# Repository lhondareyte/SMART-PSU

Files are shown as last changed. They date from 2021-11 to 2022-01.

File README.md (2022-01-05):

# SMART PSU for ARM SBC
This is a smart power switch for ARM SBC. This provides a gracefull shutdown and power-off for any tiny board computer that support FreeBSD+libgpio.

This tested OK on 
* Nanopi Neo
* Nanopi Neo Air
* Orange PI
* Raspberry PI B
* Raspberry PI 3

## How it's work?
When plugging in, the board is poweroff and the switch device enter in sleep mode to reduce power consumption.  Just press the switch to power on the board. If you press again the button within 1.5 seconds, the board is poweroff immediatly. 

In normal operation (when operating system is running), the ```psud``` daemon wait for key pressed to perform specified action. The default configuration file is as follow:

```
# psud configuration file
# $Id$  /etc/psud.conf
PSUD_PIN=3                       # My configuration on NanoPI Neo
PSUD_CMD="/sbin/shutdown -p now"	
PSUD_OPT="Dont Care"             # Nothing special
```
In ```/etc/rc.conf```, adds the following line

```
psud_enable="YES"
```
Start ```psud``` 

```
service psud start
```
So, just press button to gracefully shutdown the system. After the configured delay (by dip-switch), the board is powered-off.

## AC Recovery mode
AC Power Recovery
Allows you to set how the system reacts after AC power is restored to the system. By default, the AC Power Recovery option is set to "Power OFF". The other option is "last state".

## Nanobsd configuration
Since all persistents filesystems are mount read-only, there is no need for graceful shutdown with nanobsd. But you probably need to save your configuration on shutdown. You can achieve this with the following script:

```
#!/bin/sh
#
# file: /usr/local/bin/save_configuration.sh
#
mount /cfg || exit 1
find /cfg -type f -print | sed -e '/^\/cfg//' | while read f
do
	if [ -f /etc/$f ] ; then
		cp -p /etc/$f /cfg/$f
	fi
done
sync;sync;sync
umount /cfg
```
Edit ```/etc/psud.conf``` as follows:

```
PSUD_PIN=1                    # Power switch pin, hardware dependent
PSUD_CMD="/usr/local/bin/save_configuration.sh"

PSUD_OPT="WaitAndShot"        # Wait for $PSUD_CMD to complete before
                              # poweroff. GPIO pin is toggle to HIGH 
                              # after $CMD complete . Any other option
                              # is ignored and power off is achieved after
                              # $SHUTDOWN_TIMEOUT
```

## About files
```
 psud/        psud daemon sources
 kicad/       KiCad schematic
 firmware/    source code for AVR attiny13/13a and atmega328p
 refs/        Some MOSFET-P datasheets
```

## LICENSE
Released under the MIT License

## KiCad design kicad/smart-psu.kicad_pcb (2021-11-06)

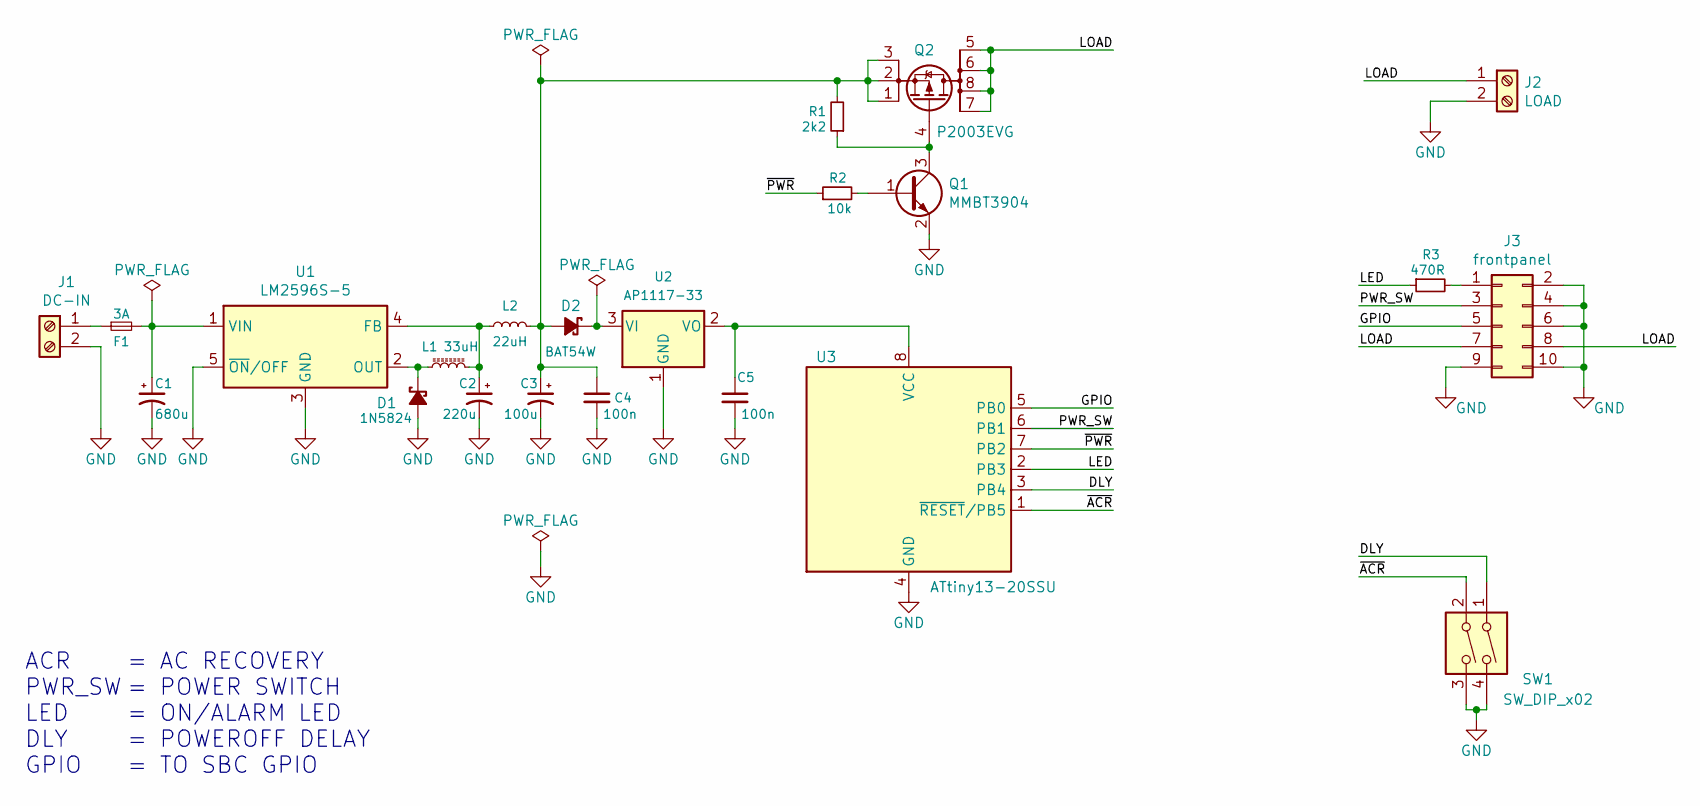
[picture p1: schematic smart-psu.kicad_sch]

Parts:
C1: 680u; C_Radial_D10.0mm_H20.0mm_P5.00mm
C2: 220u; CP_Radial_D8.0mm_P2.50mm
C3: 100u; CP_Radial_D5.0mm_P2.50mm
C4, C5: 100n; C_1206_3216Metric_Pad1.33x1.80mm_HandSolder
D1: 1N5824; D_A-405_P12.70mm_Horizontal
D2: BAT54W; D_1206_3216Metric_Pad1.42x1.75mm_HandSolder
F1: 3A; Fuse_1206_3216Metric_Pad1.42x1.75mm_HandSolder
J1: DC-IN; TerminalBlock_MetzConnect_Type055_RT01502HDWU_1x02_P5.00mm_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
J2: LOAD; TerminalBlock_MetzConnect_Type055_RT01502HDWU_1x02_P5.00mm_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
J3: frontpanel; PinHeader_2x05_P2.54mm_Vertical
L1: 33uH; L_Toroid_Vertical_L21.6mm_W11.4mm_P7.62mm_Pulse_KM-3
L2: 22uH; L_Toroid_Vertical_L21.6mm_W11.4mm_P7.62mm_Pulse_KM-3
Q1: MMBT3904; SOT-23
Q2: P2003EVG; SOIC-8_3.9x4.9mm_P1.27mm
R1: 2k2; R_1206_3216Metric_Pad1.30x1.75mm_HandSolder
R2: 10k; R_1206_3216Metric_Pad1.30x1.75mm_HandSolder
R3: 470R; R_1206_3216Metric_Pad1.30x1.75mm_HandSolder
SW1: SW_DIP_x02; SW_DIP_SPSTx02_Slide_9.78x7.26mm_W7.62mm_P2.54mm
U1: LM2596S-5; TO-263-5_TabPin3
U2: AP1117-33; SOT-223-3_TabPin2
U3: ATtiny13-20SSU; SOIC-8_3.9x4.9mm_P1.27mm

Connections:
/DLY: SW1.1, U3.3 (PB4)
/GPIO: J3.5, U3.5 (PB0)
/LED: R3.1, U3.2 (PB3)
/LOAD: J2.1, J3.7, J3.8, Q2.5 (D), Q2.6 (D), Q2.7 (D), Q2.8 (D)
/PWR_SW: J3.3, U3.6 (PB1)
/~ACR: SW1.2, U3.1 (~RESET/PB5)
/~PWR: R2.1, U3.7 (PB2)
GND: C1.2, C2.2, C3.2, C4.2, C5.2, D1.2 (A), J1.2, J2.2, J3.2, J3.4, J3.6, J3.9, J3.10, Q1.2 (E), SW1.3, SW1.4, U1.3 (GND), U1.5 (~ON/OFF), U2.1 (GND), U3.4 (GND)
unnamed: C1.1, F1.2, U1.1 (VIN)
unnamed: C2.1, L1.2, L2.2, U1.4 (FB)
unnamed: C3.1, C4.1, D2.2 (A), L2.1, Q2.1 (S), Q2.2 (S), Q2.3 (S), R1.2
unnamed: C5.1, U2.2 (VO), U3.8 (VCC)
unnamed: D1.1 (K), L1.1, U1.2 (OUT)
unnamed: D2.1 (K), U2.3 (VI)
unnamed: F1.1, J1.1
unnamed: J3.1, R3.2
unnamed: Q1.1 (B), R2.2
unnamed: Q1.3 (C), Q2.4 (G), R1.1

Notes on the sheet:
ACR PWR_SW LED DLY GPIO
= AC RECOVERY = POWER SWITCH = ON/ALARM LED = POWEROFF DELAY = TO SBC GPIO

Board: 2 copper layers, 22 parts (0 on the bottom side), 18 nets, no tracks yet.

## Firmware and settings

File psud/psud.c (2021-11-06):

/*
 * Copyright (c) 2018-2021 Luc Hondareyte
 *
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
 * THE SOFTWARE IS PROVIDED "AS IS", WITHOUT WARRANTY OF ANY KIND, EXPRESS OR
 * IMPLIED, INCLUDING BUT NOT LIMITED TO THE WARRANTIES OF MERCHANTABILITY,
 * FITNESS FOR A PARTICULAR PURPOSE AND NONINFRINGEMENT. IN NO EVENT SHALL THE
 * AUTHORS OR COPYRIGHT HOLDERS BE LIABLE FOR ANY CLAIM, DAMAGES OR OTHER
 * LIABILITY, WHETHER IN AN ACTION OF CONTRACT, TORT OR OTHERWISE, ARISING FROM,
 * OUT OF OR IN CONNECTION WITH THE SOFTWARE OR THE USE OR OTHER DEALINGS IN THE
 * SOFTWARE.
 */

#include <stdlib.h>
#include <stdio.h>
#include <unistd.h>
#include <libgpio.h>
#include <time.h>
#include <sys/time.h>
#include <sys/resource.h>
#include <signal.h>
#include <sys/file.h>
#include <sys/types.h>
#include <sys/wait.h>
#include <syslog.h>

#include "psud.h"
#include "config.h"

FILE *lockfile;

struct config psu_config;

void psud_quit(int r) {
	if ( r == SIGHUP ) {
		get_config(CONFILE, &psu_config);
		syslog(LOG_NOTICE,"Waiting on pin %s for action (%s/%s).\n", psu_config.pin, psu_config.cmd, psu_config.opt);
		return;
	}
	syslog(LOG_NOTICE,"Signal received (%d), quitting.\n", r);
	fclose(lockfile);
	remove (LOCK);
	closelog();
	exit(0);
}

int main(int argc, char **argv) {

	int status=0;

	/*
	 * Open exclusive lock file to avoid multiple instances of daemon
	 */
	if (( lockfile = fopen(LOCK, "w")) == NULL) {
		perror(LOCK);
		return 1;
	}
	if (flock (fileno(lockfile), LOCK_EX | LOCK_NB) == -1) {
		perror (LOCK);
		return 1;
	}

	/*
	 * Getting valid configuration
	 */
	if (( get_config(CONFILE, &psu_config)) == -1 ) {
		fprintf (stderr, "Error getting configuration.\n");
		return 1;
	}

	/*
	 * Logging
	 */
	openlog("psud", LOG_PID|LOG_NDELAY, LOG_DAEMON),
		syslog(LOG_NOTICE, "Starting daemon.\n");

	/*
	 * Signals handling
	 */
	signal(SIGHUP, psud_quit);
	signal(SIGINT, psud_quit);
	signal(SIGTERM, psud_quit);

	/*
	 * Daemonize
	 */
	pid_t process_id=0;
	if ((process_id = fork()) < 0) {
		perror("fork");
		exit(1);
	}
	// Kill parent process
	if (process_id > 0 )
		exit(0);

	/*
	 * Writing pid to lockfile
	 */
	setvbuf (lockfile, (char*)NULL, _IONBF, 0);
	pid_t pid=getpid();
	fprintf(lockfile, "%d", pid);
	setpriority(PRIO_PROCESS, pid, 20);

	/*
	 * Ready to run. 
	 */
	int psu_pin = atoi(psu_config.pin);
	int buttonstate=UP;
	gpio_handle_t handle;
	if (( handle = gpio_open(0)) == -1) {
		syslog(LOG_NOTICE,"Error : No GPIO found on this platform.\n");
		//psud_quit(15);
	}

	gpio_pin_input(handle, psu_pin);
	gpio_pin_low(handle, psu_pin);
	gpio_pin_pullup(handle, psu_pin);

	syslog(LOG_NOTICE,"Waiting on pin %s for action (%s/%s).\n", psu_config.pin, psu_config.cmd, psu_config.opt);

	// Polling for key pressed
	while(1) {
		buttonstate = gpio_pin_get(handle, psu_pin);
		if ( buttonstate == DOWN ) {

			pid_t pid=0;
			if ((pid = fork()) == -1)
				perror("fork error");
			else if (pid == 0) {
				syslog(LOG_NOTICE, "GPIO %d toggle: Executing PSUD_CMD (%s).\n", psu_pin, (char*)psu_config.cmd);
				execl("/bin/sh", "sh", "-c", (char*)psu_config.cmd, NULL);
				syslog(LOG_NOTICE, "execl error\n");
				continue;

			} 
			if (strcmp(psu_config.opt, "WaitAndShoot") == 0 ) {
				syslog(LOG_NOTICE, "Waiting for child process(%d).\n", pid);
				waitpid(pid, NULL, WEXITED);
				// Toggle pin from ouput and high level to shutoff
				gpio_pin_output(handle, psu_pin);
				gpio_pin_high(handle, psu_pin);
				psud_quit(15);
			}
			wait(&status);
		}
		usleep(250000);
	}	
}

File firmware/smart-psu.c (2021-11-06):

/*
 * Copyright (c) 2018-2021 Luc Hondareyte
 *
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
 * THE SOFTWARE IS PROVIDED "AS IS", WITHOUT WARRANTY OF ANY KIND, EXPRESS OR
 * IMPLIED, INCLUDING BUT NOT LIMITED TO THE WARRANTIES OF MERCHANTABILITY,
 * FITNESS FOR A PARTICULAR PURPOSE AND NONINFRINGEMENT. IN NO EVENT SHALL THE
 * AUTHORS OR COPYRIGHT HOLDERS BE LIABLE FOR ANY CLAIM, DAMAGES OR OTHER
 * LIABILITY, WHETHER IN AN ACTION OF CONTRACT, TORT OR OTHERWISE, ARISING FROM,
 * OUT OF OR IN CONNECTION WITH THE SOFTWARE OR THE USE OR OTHER DEALINGS IN THE
 * SOFTWARE.
 */
/*
 * POWER BUTTON - AVR Version
 *
 * Copyright (c)2018-2021, Luc Hondareyte
 * All rights reserved.
 *
 * $Id$
 */

#include "smart-psu.h"

uint8_t pwr_state=OFF;
uint8_t os_is_running=NO;

void ms_wait (uint8_t n) {
	while (n) {
		_delay_us(1000);
		n--;
	}
}

inline void shutdown (void) {
#if defined (__BREADBOARD__)
	setBit(O_PORT,GPIO);
	ms_wait(250);
	clearBit(O_PORT,GPIO);
#else
	clearBit(O_PORT,GPIO);
	ms_wait(250);
	setBit(O_PORT,GPIO);
#endif
	ms_wait(250);
	clearBit(D_PORT,GPIO);    // Wait feedback from SBC
}

inline void PowerOff (void) {
	clearBit(O_PORT,GPIO);
	setBit(D_PORT,GPIO);      // no need feedback from SBC
	switchOff();
}

void startTimer (uint16_t n) {
	ms_seconds = n;
	ticks = 0;
	// No prescaler
	TCCR0B = 0x01;
}

void stopTimer(void) {
	ms_seconds = 0x0000;
	ticks = 0;
	TCCR0B = 0x00;
}

/* Blinking a led */

inline void blink (uint8_t pin, uint8_t n) {
	while(n) {
		ms_wait(250);
		toggleBit(O_PORT, pin);
		n--;
	}
	clearBit(O_PORT, pin);
}

void setupHardware (void ) {

        // Set ports direction
        setBit(D_PORT,FAULT);     // Fault alarm
        setBit(D_PORT,PWR);       // MOSFET Trigger
        setBit(D_PORT,GPIO);      // To SBC GPIO
        clearBit(D_PORT,PWR_SW);  // Power switch
        clearBit(D_PORT,ACR);     // AC Recovery mode
        // Pullup resistor on input pins
        setBit(O_PORT,PWR_SW);
        setBit(O_PORT,ACR);

        // Configure INT0
        clearBit(INTRGST,ISC00);
        clearBit(INTRGST,ISC01);
        enable_INT0();
#if defined (__BREADBOARD__)
        CLKPR=0x00;
#endif

        // Configure TIMER0 interuption
        TIMSK0 |= (1<<TOIE0);
}

ISR (INT0_vect) {
	// Wake-up MCU on key pressed
}

#if defined (__AVR_ATtiny13A__) || defined (__AVR_ATtiny13__)
ISR (TIM0_OVF_vect)
#else
ISR (TIMER0_OVF_vect)
#endif
{
	ticks++;
	if ( ticks == TICKS ) {
		ticks = 0;
		ms_seconds--;
	}
}

static void Power (void) {

	/*  Board is ON */

	if (pwr_state == ON) {
		if (os_is_running == YES) {
			setBit(O_PORT,FAULT);
			shutdown();
			startTimer(SHUTDOWN_TIMEOUT);
			while ( ms_seconds > 0 ) {
				if (bit_is_set(I_PORT,GPIO)) {
					stopTimer();
				       	break;
				}
			}
			pwr_state=OFF;
#if defined (__AC_RECOVERY__)
			saveConfiguration(pwr_state);
#endif
			os_is_running=NO;
			clearBit(O_PORT,FAULT);
			PowerOff();
			clearBit(O_PORT,FAULT);
		}
	
	}
	/* Board is OFF */
	else {
		switchOn();
		pwr_state=ON;
#if defined (__AC_RECOVERY__)
		saveConfiguration(pwr_state);
#endif
		loop_until_bit_is_set(I_PORT,PWR_SW);
		ms_wait(250);
		os_is_running=YES;
		startTimer(STARTUP_TIMEOUT);
#if defined (__BREADBOARD__)
		setBit(O_PORT,FAULT);
#endif
		while (ms_seconds > 0) {
			if ( bit_is_clear(I_PORT,PWR_SW)) {
				stopTimer();
				pwr_state=OFF;
#if defined (__AC_RECOVERY__)
				saveConfiguration(pwr_state);
#endif
				switchOff();
				alarm(10);
				break;
			}
		}
#if defined (__BREADBOARD__)
		clearBit(O_PORT,FAULT);
#endif
	}
	stopTimer();
}

int main(void) {

	ticks = 0;
	ms_seconds = 0;
	setupHardware();

	/* Wait for PSU stabilization */
        blink (PWR, 8);

#if defined (__AC_RECOVERY__)
	if (bit_is_set(I_PORT, ACR)) {
		pwr_state=OFF;
	}
	else {
		pwr_state = loadConfiguration();
		if ( pwr_state > 0x00 ) pwr_state = ON;
	}
#else
	pwr_state=OFF;
#endif
	os_is_running=NO;
	switchOff();
	set_sleep_mode(SLEEP_MODE_PWR_DOWN);

	/*
	 * main loop
	 */
	while (1) {
		enable_INT0();
		sleep_enable();
		sei();
		sleep_cpu();
		/*
		 * zzzzz
		 */
		sleep_disable();
		disable_INT0();
		Power();
		loop_until_bit_is_set(I_PORT,PWR_SW);
		_delay_ms(250);
	}
}

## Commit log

2018-01-09 Adding kicad files
    [power-button.kicad_pcb, power-button.sch]
2018-02-02 Disable INT0 while switch is not released.
2018-02-03 Adding new layout in schematic.
    [power-button.sch]
2018-02-06 Set footprint for all components.
    [power-button.sch]
2018-03-24 Change pinout according to new design
    [power-button.sch]
2018-03-25 Adding buttond.c : POC Ok
2018-03-25 Power switch on INT0
    [smart-psu.sch]
2018-04-01 Adding sample config file
2018-04-11 Wait for child process before continue. Adding psud_opt WaitAndShoot.
    [smart-psu.kicad_pcb]
2018-04-22 Avoid double exec + indentation
    [psud.c]
2018-05-26 Update schematic for high-side switch.
    [smart-psu.sch]
2018-06-22 Adding some P-channel MOSFET datasheets.
2018-08-03 Upgrade to Kicad 5.0
    [smart-psu.sch]
2018-10-06 Adding AC recovery configuration pin.
    [smart-psu.sch]
2019-03-10 Accidentaly delete rescue-lib
    [smart-psu.sch]
2021-01-26 Fix segfault on config parse. get_config() return an error if some vars are missing.
    [psud.c]
2021-03-31 Update schematic
    [smart-psu.sch]
2021-04-01 Add fault on quick power off.
2021-04-01 Update Makefile to create fuses.txt for attiny13
2021-11-06 Waiting for PSU stabilization and fix compilation with avr-gcc 10.2 (need more fixs)
    [smart-psu.c, smart-psu.h]
2021-11-06 Update frontpanel connector
    [smart-psu.kicad_pcb, smart-psu.sch]
2023-02-12 Update to KiCad 6
    [smart-psu.kicad_sch, smart-psu.sch]
